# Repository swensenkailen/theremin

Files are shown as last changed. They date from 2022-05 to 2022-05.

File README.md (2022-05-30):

# theremin
Development repo for embedded Arduino theremin project by Kailen Swensen and Will McDonald

A wiring diagram is provided in the [build documentation](/docs/README.md)

### Enclosure
[enclosure documentation](/enclosure/README.md)

### Sensor Test
[test documentation](/sensor-test/README.md)

### Button Test
[test documentation](/button-test/README.md)

### Audio Output Test
[test documentation](/audio-out-test/README.md)

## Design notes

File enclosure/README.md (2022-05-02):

There are currently only files to support building the theramin inside of a cardboard box.  We plan to design a fully 3d printed enclosure in the future.

## Cardboard Enclosure
For prototyping, we have created an enclosure using an adafruit box.  3d printed brackets were used to help secure the buttons and usb panel mount.

### Button Panel Sketch
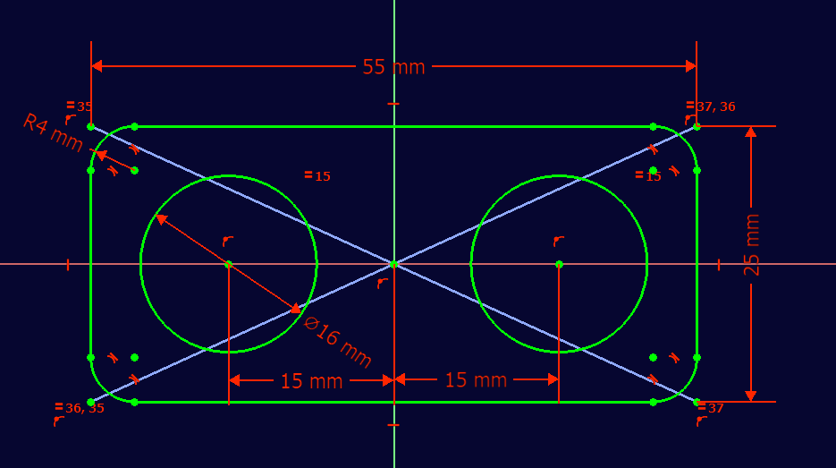
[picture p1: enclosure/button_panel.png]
button panel


### USB B Panel Mount Support Sketch
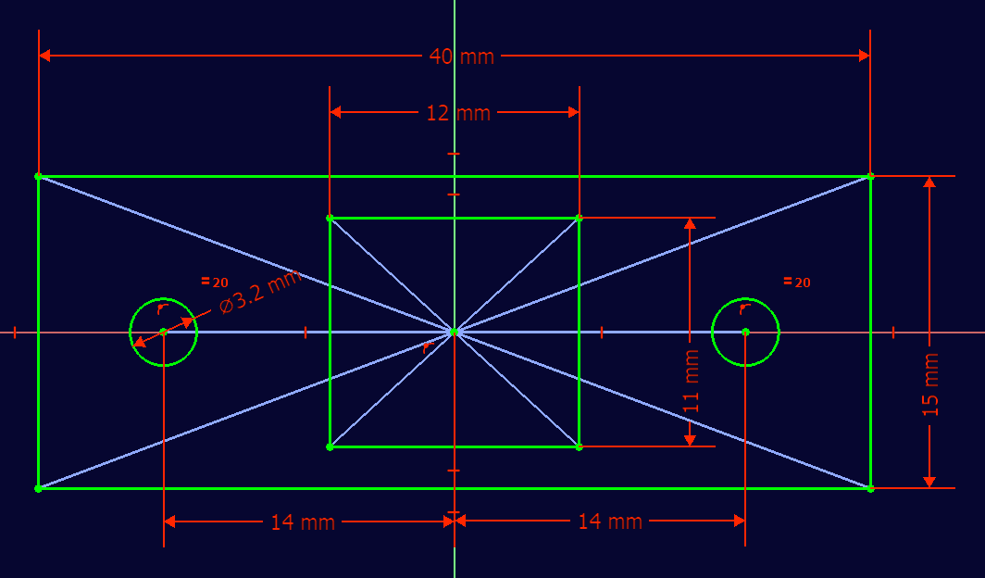
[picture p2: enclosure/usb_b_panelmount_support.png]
usb b panel mount


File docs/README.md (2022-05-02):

A KiCad project is included, containing the used wiring diagram, and a proposed PCB design.

## Wiring Diagram:
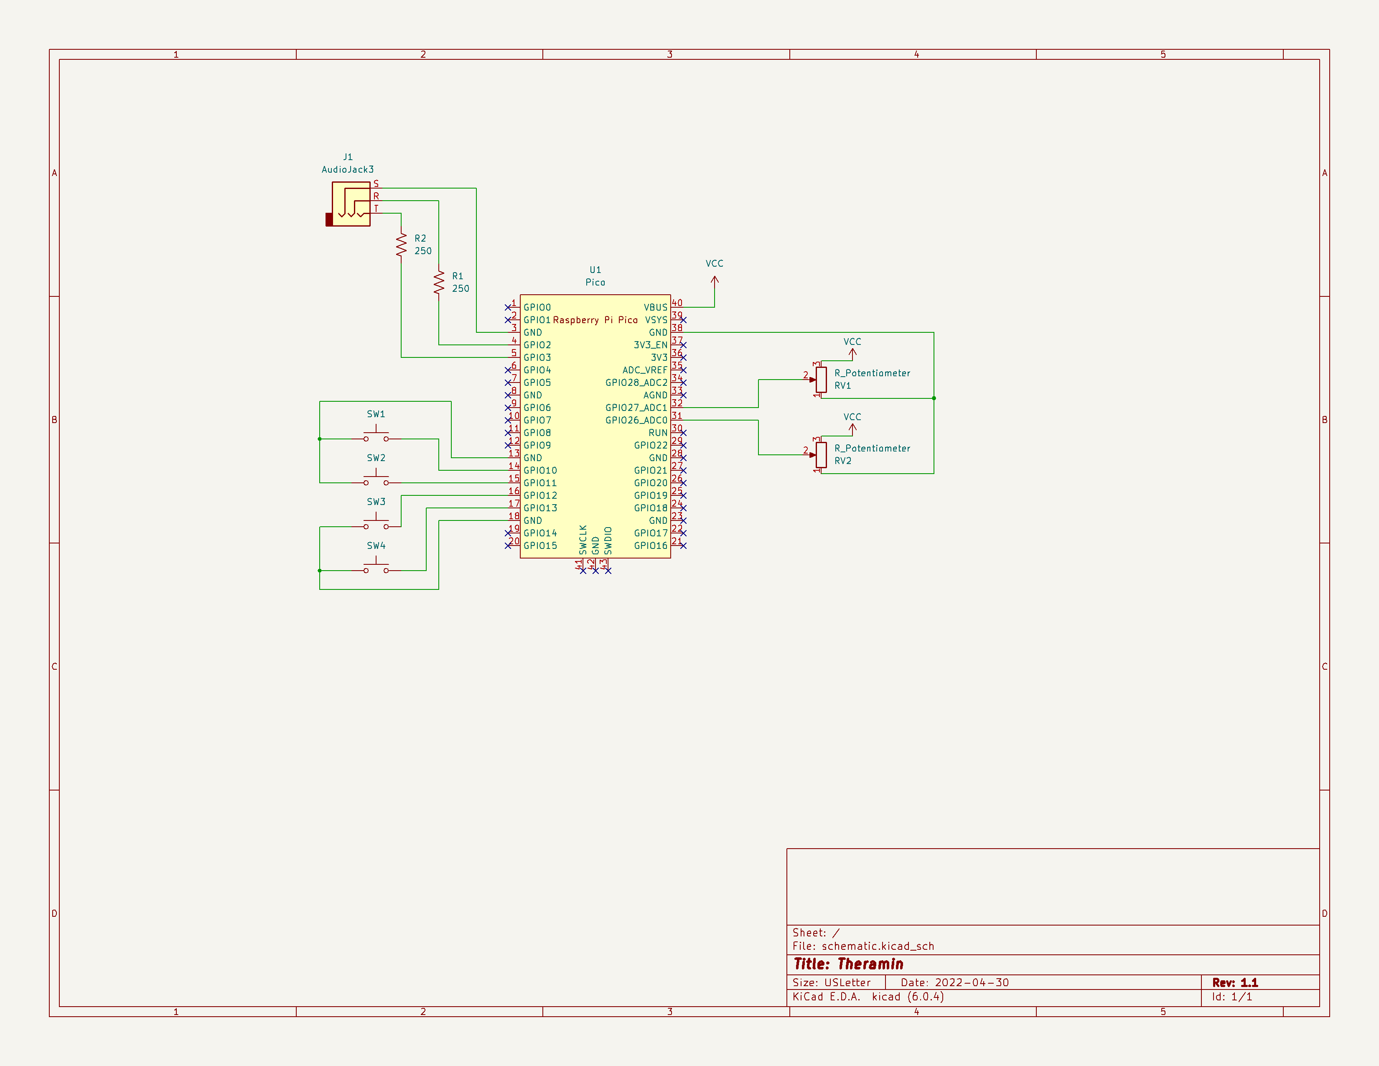
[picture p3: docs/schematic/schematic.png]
wiring diagram


The Raspberry Pi Pico symbols footprints were sourced from [this repo](https://github.com/ncarandini/KiCad-RP-Pico/).  No modifications were made.

License [here](https://github.com/ncarandini/KiCad-RP-Pico/blob/dc6f9b9f213dc36eebce626aa9ee72a333fa0db3/LICENSE)

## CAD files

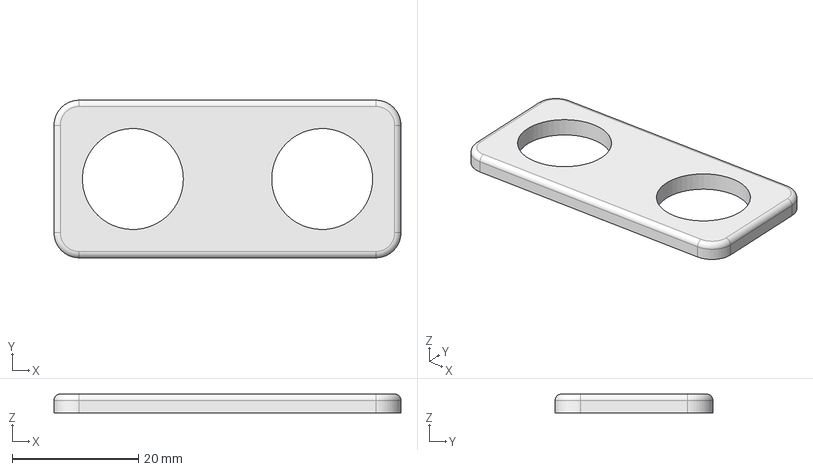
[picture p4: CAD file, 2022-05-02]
enclosure/freecad/button_panel.FCStd
55.0 x 25.0 x 3.00 mm

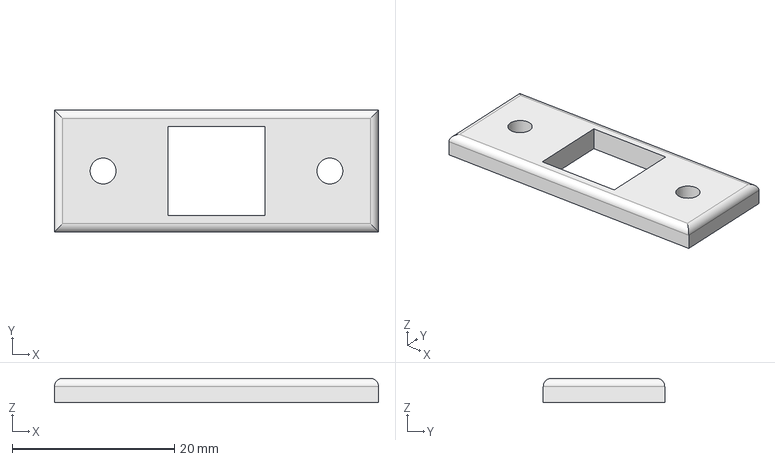
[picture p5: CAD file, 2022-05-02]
enclosure/freecad/usb_b_panelmount_support.FCStd
40.0 x 15.0 x 3.00 mm

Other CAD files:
enclosure/button_panel.3mf
enclosure/button_panel.stl
enclosure/usb_b_panelmount_support.3mf
enclosure/usb_b_panelmount_support.stl

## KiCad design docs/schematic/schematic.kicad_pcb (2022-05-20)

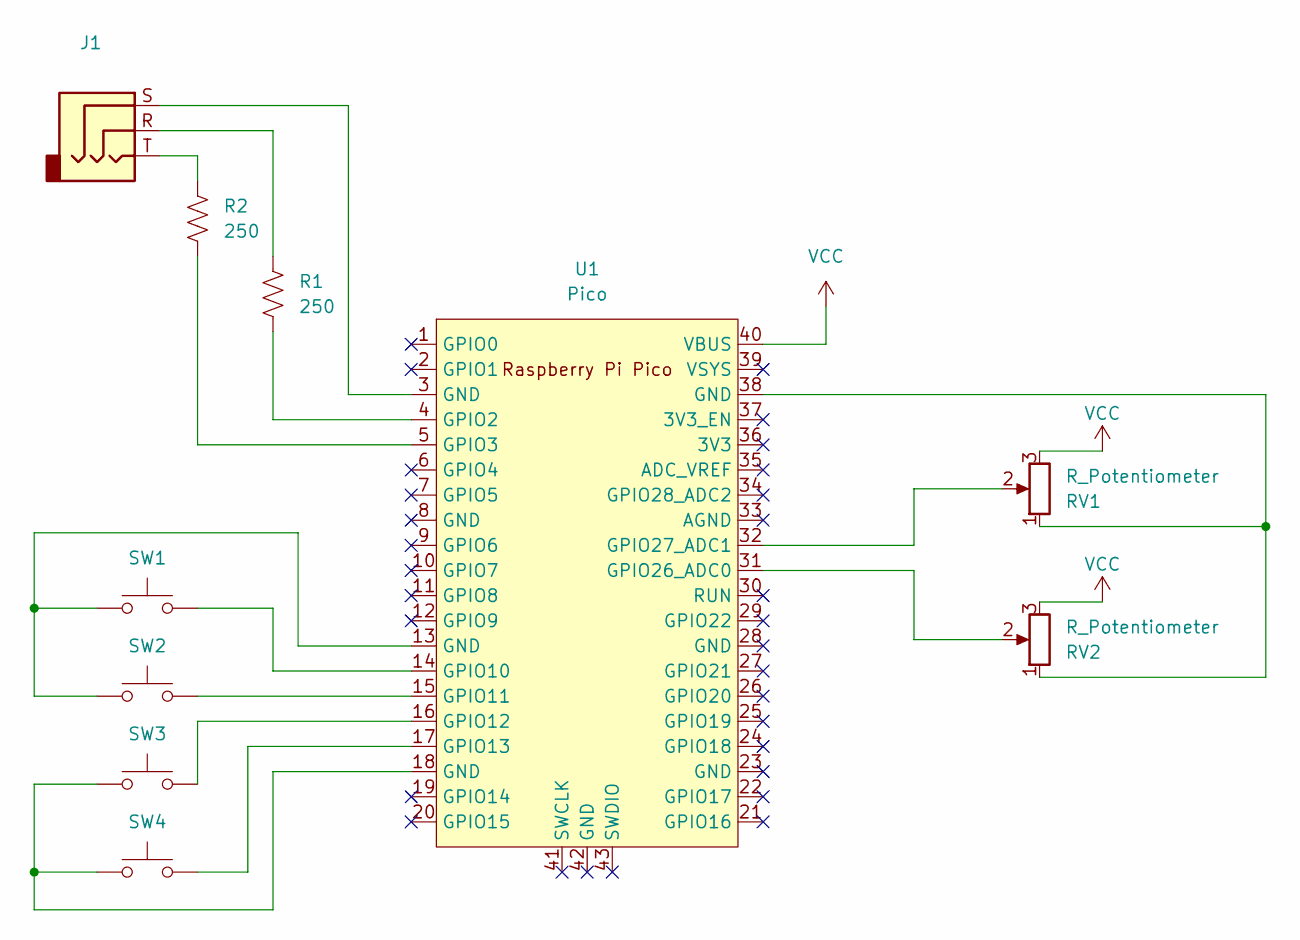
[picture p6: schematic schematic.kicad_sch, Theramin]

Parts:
J1: (no value)
R1, R2: 250; R_Axial_DIN0309_L9.0mm_D3.2mm_P15.24mm_Horizontal
RV1, RV2: R_Potentiometer; SolderWire-0.5sqmm_1x03_P4.6mm_D0.9mm_OD2.1mm
SW1, SW2, SW3, SW4: SW_Push; SolderWire-0.15sqmm_1x02_P4mm_D0.5mm_OD1.5mm
U1: Pico; RPi_Pico_SMD_TH

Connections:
unnamed: J1.R, R1.1
unnamed: J1.S, U1.3 (GND)
unnamed: J1.T, R2.1
unnamed: R1.2, U1.4 (GPIO2)
unnamed: R2.2, U1.5 (GPIO3)
unnamed: RV1.1, RV2.1, U1.38 (GND)
unnamed: RV1.2, U1.32 (GPIO27_ADC1)
unnamed: RV2.2, U1.31 (GPIO26_ADC0)
unnamed: SW1.1, SW2.1, U1.13 (GND)
unnamed: SW1.2, U1.14 (GPIO10)
unnamed: SW2.2, U1.15 (GPIO11)
unnamed: SW3.1, SW4.1, U1.18 (GND)
unnamed: SW3.2, U1.16 (GPIO12)
unnamed: SW4.2, U1.17 (GPIO13)
VCC: RV1.3, RV2.3, U1.40 (VBUS)

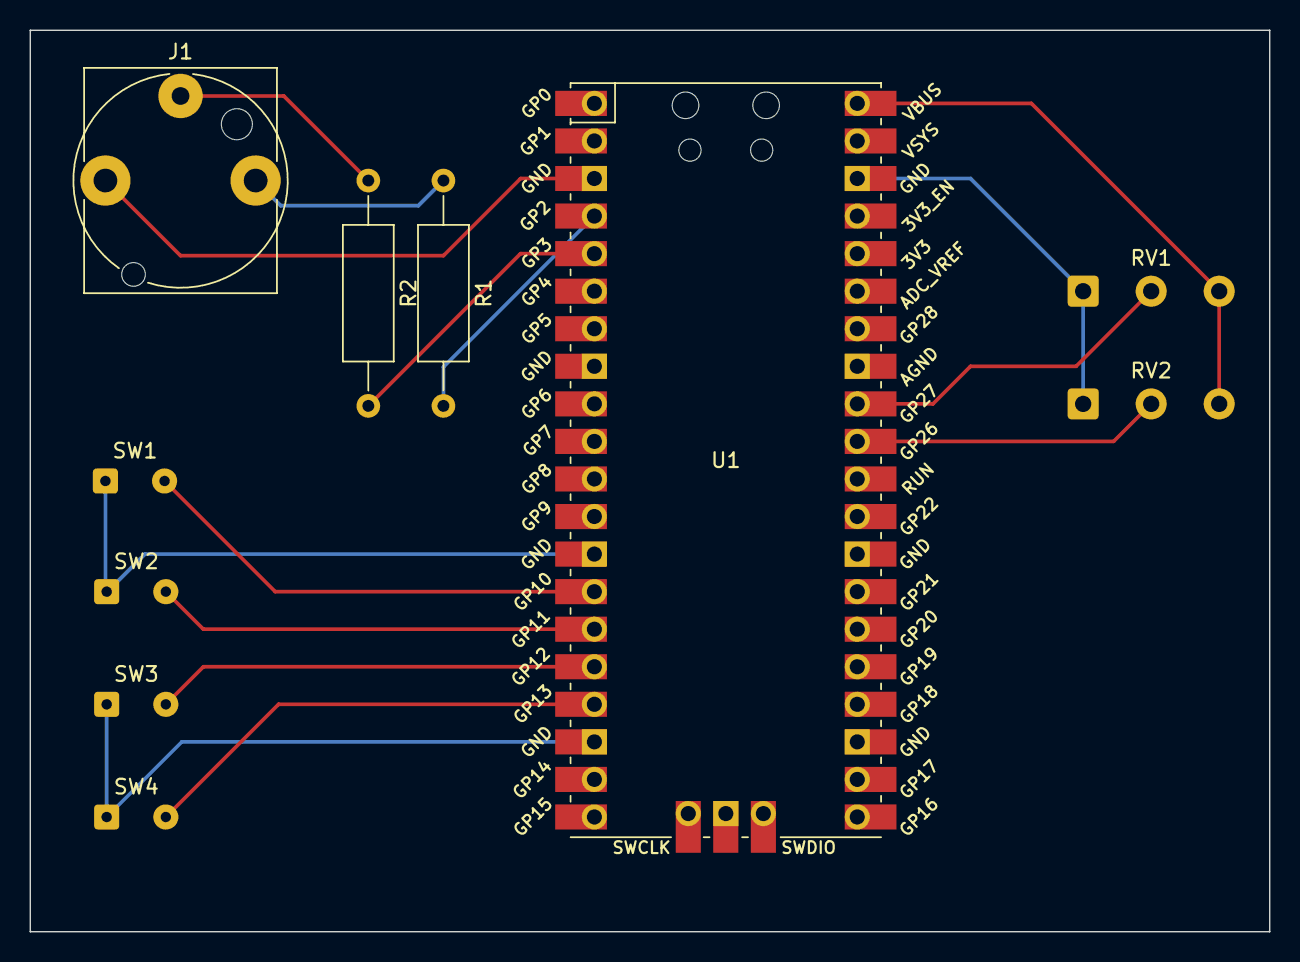
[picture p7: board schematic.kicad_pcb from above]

Board: 2 copper layers, 83.8 x 61.0 mm, 10 parts (0 on the bottom side), 15 nets.

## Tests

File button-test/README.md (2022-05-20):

## Button Test

A simple test of button functionality with adjusted debouncing gaps for increased response to quick presses/releases.

### BOM:
- Raspberry Pi Pico
- 4x Adafruit panel mount 16mm momentary buttons

### Libraries
[Arduino Button Library](https://github.com/ubugnu/Arduino/tree/master/Button)

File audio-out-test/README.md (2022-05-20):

## Audio Output Test

An audio test with a simple frequency sweeper. Test class makes use of the Arduino tone() functionality, with customizable sweep range, delay period, and frequency rate of change.

### BOM:
- Raspberry Pi Pico
- 6.35mm Stereo audio socket connector

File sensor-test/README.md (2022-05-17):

## Sensor Test
As a step towards building the complete project we first tested the implementation of data collection from one sensor.  This allowed us to verify that we were getting the values we expected, and gave us a chance to refine our data manipulation.  Some of what we learned is detailed at the bottom of this document.

### Voltage Calibration
From the RP2040 datasheet, the board has a 12 bit ADC, with a maximum voltage of 3.3v.  To convert the 12 bit unsigned ADC value to voltage, we can use `3.3 * adc / 1 << 12`

### Sensor Calibration
From the datasheet of the distance sensor used, I used excel to create a scatterplot of the data given.  I then used the trendline function to generate a formula for the distance between the object and the sensor, given the voltage the ADC was reading.

The formula this generated for our sensor was: `distance = 12.472 / voltage ^ -1.068`

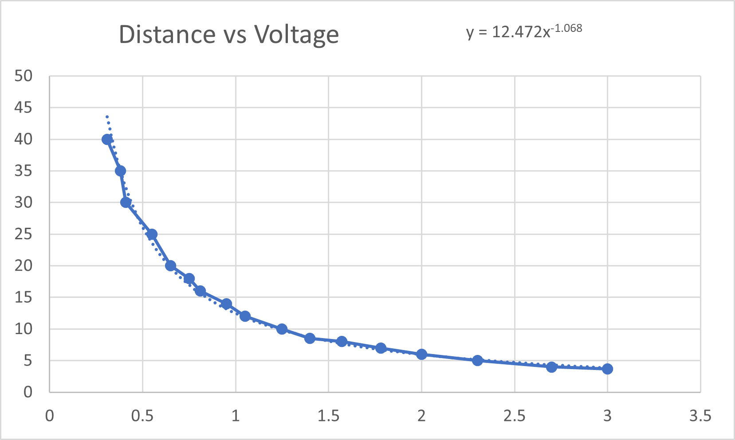
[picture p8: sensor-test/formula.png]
plot of sensor distance vs voltage


### BOM:
- Raspberry Pi Pico
- Sharp GP2Y0A41SK0F IR distance sensor

### Wiring Diagram:
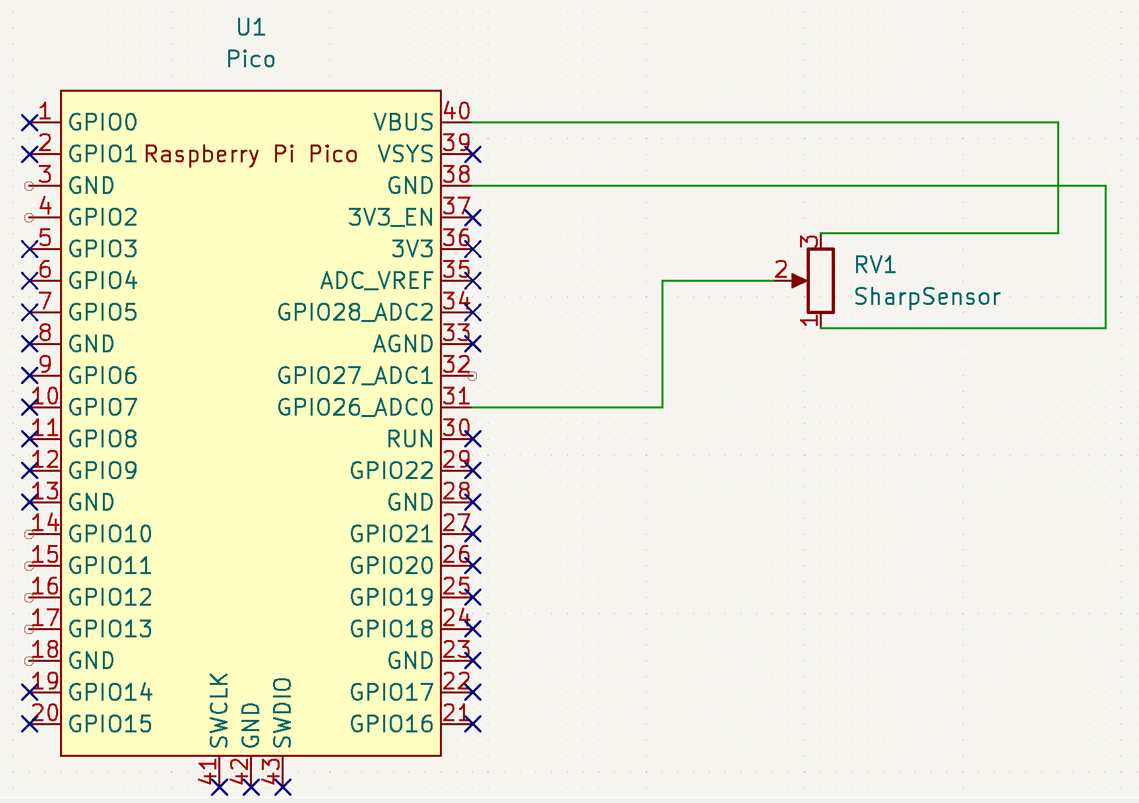
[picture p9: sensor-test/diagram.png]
diagram of circuit used for testing


#### Learning points
We discovered issues in the upload process using Arduino IDE 1.8.16, which we resolved by using a more recent version of the IDE, 2.0.0 rc-6.

We also learned that some of our assumptions about the functionality of analogRead were incorrect.  We had believed that analogRead would return an integer with the full resolution of the RP2040 adc, but instead found that the return values only ranged from 0 to 1024.  I found that for compatibility, arduino defaults to 10bit adc.  We found the solution to our issue in the arduino documentation of analogRead(), which explained we could use analogReadResolution() to set the resolution to the RP2040 ADC resolution of 12 bits.

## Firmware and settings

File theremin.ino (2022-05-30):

/**
 * @author Kailen Swensen, Will McDonald
 * @date   May 2022
 * @brief  Arduino theremin with MIDI output
 * Written for RP2040
 */

// #include <Button.h>
#include "IrDistanceSensor.h"


#define PIN_SENS_L A0
#define PIN_SENS_R A1

#define PIN_BUTTON_1 10
#define PIN_BUTTON_2 11
#define PIN_BUTTON_3 12
#define PIN_BUTTON_4 13

// Button button1(PIN_BUTTON_1),
//        button2(PIN_BUTTON_2),
//        button3(PIN_BUTTON_3),
//        button4(PIN_BUTTON_4);


#define LOGGING_DELAY 50
int last_log_millis = 0;

IrDistanceSensor_Relative sensor_left(PIN_SENS_L),
                          sensor_right(PIN_SENS_R);

void setup()
{

  // TODO: use Kails button library
  // pinMode(PIN_BUTTON_1, INPUT_PULLUP);
  // pinMode(PIN_BUTTON_2, INPUT_PULLUP);
  // pinMode(PIN_BUTTON_3, INPUT_PULLUP);
  // pinMode(PIN_BUTTON_4, INPUT_PULLUP);

  SerialUSB.begin(9600);

  sensor_left.Init();
  sensor_right.Init();
}

void loop()
{
  sensor_left.sensorLoop();
  sensor_right.sensorLoop();

  unsigned long curr_millis = millis();
  if (curr_millis - last_log_millis > LOGGING_DELAY) {
    SerialUSB.print("Left Sensor: ");
    SerialUSB.println(sensor_left.GetDistance());
    SerialUSB.print("Right Sensor: ");
    SerialUSB.println(sensor_right.GetDistance());
  }

  delay(10);
}

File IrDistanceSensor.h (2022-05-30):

/**
 * @file IrDistanceSensor.h
 * @author Will McDonald
 * @brief Interface Class for Sharp IR distance sensors
 * @version 0.1
 * @date 2022-05-19
 * 
 */

// #include <math.h>

#ifndef SMOOTHING_SAMPLES
#define SMOOTHING_SAMPLES (3u)
#endif

#ifndef SENSOR_PERIOD
#define SENSOR_PERIOD (40u) // minimum time allowed between samples
#endif

#ifndef SENSOR_COEFF
#define SENSOR_COEFF (12.472f)
#endif

#ifndef SENSOR_EXPONENT
#define SENSOR_EXPONENT (-1.068f)
#endif

#define ADC_TO_VOLTS 3.3f / ((0x01 << ADC_RESOLUTION)) // max voltage div by max val

// NOTE: it is possible for the sum to overflow, if 1 << sizeof(int) - ADC_RESOLUTION is less than SMOOTHING_SAMPLE_COUNT.
// this should not be the case, as RP2040 ADC_RESOLUTION = 12bits and int >= 16bits.  giving us more than enough samples for smoothing.

class IrDistanceSensor
{
private:
  int _pin = 0;

  int samples[SMOOTHING_SAMPLES] = { 0 };
  int curr_sample = 0;

  unsigned long last_sample_millis = 0;

  void storeSample(int sample)
  {
    samples[curr_sample++] = sample;

    if (curr_sample >= SMOOTHING_SAMPLES)
    {
      curr_sample = 0;
    }
  }

  int getSmoothed(void)
  {
    int sum = 0;

    for (int i = 0; i < SMOOTHING_SAMPLES; ++i)
    {
      sum += samples[i];
    }

    return sum / SMOOTHING_SAMPLES;
  }

  int readADC(void)
  {
    // TODO: consider pushing/popping ADC resolution, Other libraries/ user code may be expecting a different value.
    analogReadResolution(ADC_RESOLUTION);
    return analogRead(_pin);
  }

public:
  IrDistanceSensor(int pin) : _pin(pin)
  {
  }

  void Init(void)
  {
    pinMode(_pin, INPUT);
    analogReadResolution(ADC_RESOLUTION);

    for (int i = 0; i < SMOOTHING_SAMPLES; ++i) {
      storeSample(analogRead(_pin));
      delay(SENSOR_PERIOD);
    }
  }

  void sensorLoop(void)
  {
    unsigned long curr_millis = millis();

    if (curr_millis - last_sample_millis > SENSOR_PERIOD)
    {
      storeSample(analogRead(_pin));
      last_sample_millis = curr_millis;
    }
  }

  float GetDistance(void)
  {
    return SENSOR_COEFF * pow(getSmoothed() * ADC_TO_VOLTS, SENSOR_EXPONENT);
  }
};

class IrDistanceSensor_Relative : public IrDistanceSensor {
private:
  int low = 0, high = 2000;

public:
  IrDistanceSensor_Relative(int pin) : IrDistanceSensor(pin)
  {
  }

  void SetLow(void)
  {
    low = IrDistanceSensor::GetDistance();
  }

  void SetHigh(void)
  {
    high = IrDistanceSensor::GetDistance();
  }

  float GetDistance(void)
  {
    float val = IrDistanceSensor::GetDistance() / (high - low);
    return min(1, max(val, 0)); // clamp
  }
};

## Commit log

2022-04-30 Modelled a bracket for the USB port
    Created a bracket to support the USB type B panel mount to USB micro B adapter cable. Will be 3d printed to use in cardboard box prototype enclosure.
    [usb_b_panelmount_support.3mf, usb_b_panelmount_support.FCStd, usb_b_panelmount_support.stl]
2022-05-01 KiCad project
    Added KiCad Project with wiring diagram and PCB design for theramin.
    Included License for used KiCad libraries.
    [schematic.kicad_pcb, schematic.kicad_sch]
2022-05-01 Button bracket for cardboard prototype
    Modeled brackets to support 16mm momentary pushbuttons in a carboard enclosure.
    [button_panel.3mf, button_panel.FCStd, button_panel.stl]
2022-05-01 Updated USB panel mount for screw fitment
    When printed, the fitment of the bracket was too tight on the screws. I have adjusted the freecad document and updated the files for a better fit.
    [usb_b_panelmount_support.3mf, usb_b_panelmount_support.FCStd, usb_b_panelmount_support.stl]
2022-05-01 Updated Enclosure README, added images
    Explained the current situation regarding the enclosure, and included schematic images from FreeCad
2022-05-02 Updated arduino c++ file
    Added template i/o code for the arduino board
2022-05-05 Sensor Data Collection Test
    Successfully proved the ability to collect calibrated data from one sensor.
    Remapped ADC data to voltage, then from voltage to distance in cm.
    Change in distance will now be able to be represented linearly.
2022-05-05 Sensor Test Documentation
    Documented purpose, methods, learning of test
2022-05-19 Button test
    Tests functionality of 4 attached buttons on prototype theremin
2022-05-19 Update Schematic to as built
    We deviated from the original schematic as it was simpler to construct/ source in the way we built it.
    [schematic.kicad_pcb, schematic.kicad_sch]
2022-05-20 Configured build caching
    Configured caching for VSCode Arduino extension to reduce build time.
2022-05-20 First Pass of IrDistanceSensor Class
    Implemented a class to simplify implementation of sensor data use.
    Sensor calibration can be configured using `#define`'s. Default configuration is for Sharp GP2Y0A21YK0F IR Sensors.
    I do not have hardware on hand, so this has yet to be tested. It is written based on my successfully tested `sensor-test`.
2022-05-20 Updated README
    added BOM for button-test
2022-05-20 Update IrDistanceSensor.h
    Corrected Clamping
    [IrDistanceSensor.h]
2022-05-30 Added Buttons class
    More compact version of Button class used in button-test, made for a circuit with four buttons and defaulted to fit our prototype model.
2022-05-30 Updated readme
    Added links to button and audio output test documentation
